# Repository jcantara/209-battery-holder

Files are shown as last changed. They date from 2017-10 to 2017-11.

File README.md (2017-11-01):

# 3D printable cylindrical battery cell holder

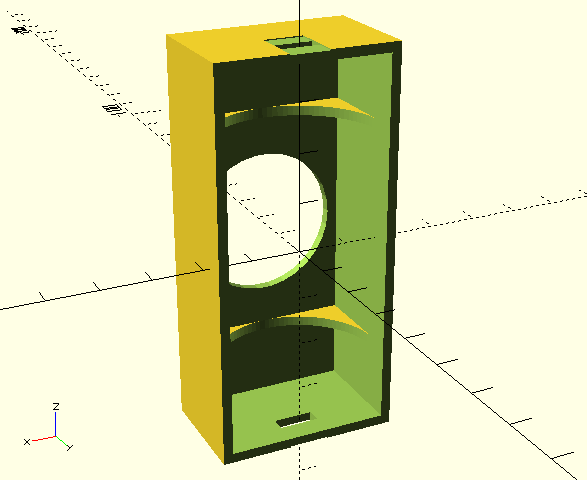
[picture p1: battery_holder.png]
holder-rendering

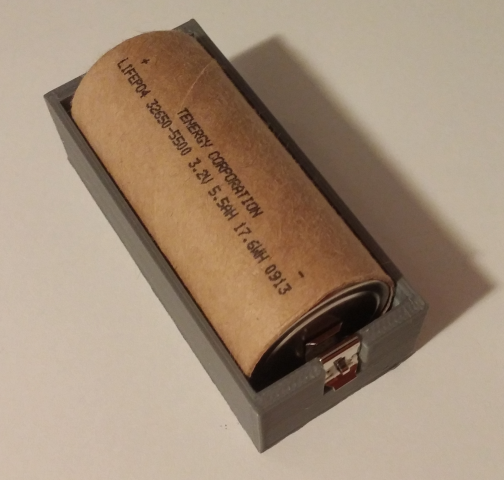
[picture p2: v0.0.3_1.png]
holder-printed

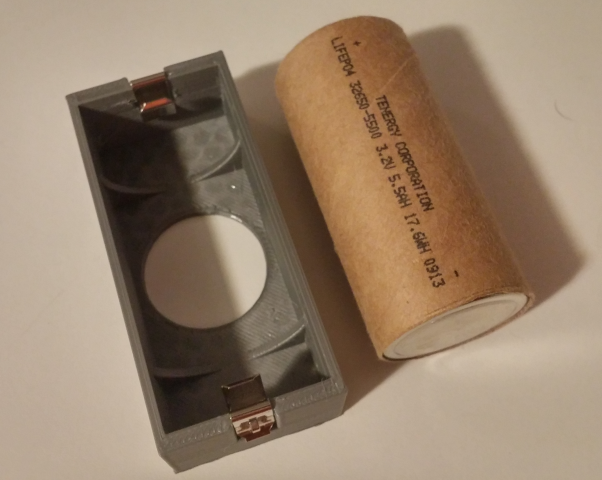
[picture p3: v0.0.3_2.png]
holder-printed2


[Thingiverse thing](https://www.thingiverse.com/thing:2615710)

This is a 3d-printable battery cell holder for cylindrical type cells, currently configured for 32650 LiFePo4 cells which I could not find any existing holders for, however should be fine with adjusted parameters for any 18650 cells, or other "standard" size cylindrical cells such as 18650, D, C, A, etc. This holder is designed around the Keystone 209 battery spring clip, available quite inexpensively from many online electronics parts warehouses such as Digikey, Jameco, Mouser, or others.

## Getting Started

The template is written for OpenSCAD, so you'll need that. It's mostly parameterized, so changing it for other batteries should work out easily. I've printed out the initial version and made some additional tweaks.

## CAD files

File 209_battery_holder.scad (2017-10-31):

// printer-specific fudge setting to allow enough clearance
diameter_fudge = 0.4;

// cell dimensions, measured to 32650 cell in-hand
cell_diameter = 33 + diameter_fudge;
cell_height = 70;

// configured for Keystone "209" clip:
clip_gap = 3.5; // gap between wall of holder and battery where spring clip sits, compressed size
clip_wall = 1.78; // width of printed wall onto which clip clips
clip_top_wall_to_hook = 4.6; // minimum distance between edge of clip wall and hook on clip
clip_width = 8.5;
clip_height = 11.5;

// holder dimensions
wall_thickness = 2.0;
end_wall_thickness = 3.5;

// calculated dimensions
box_width = cell_diameter + wall_thickness*2;
box_height = cell_height + clip_gap*2 + end_wall_thickness*2;
box_depth = cell_diameter + wall_thickness*2;
hole_width = cell_diameter;
hole_height = cell_height + clip_gap*2;
hole_depth = cell_diameter;

// transparent battery image
module battery(cell_height, cell_diameter) {
    cylinder(h=cell_height, d=cell_diameter, center=true, $fn=100);
}
//%battery(cell_height, cell_diameter);


difference(){
    // positive shapes
    union(){
        // main box shape
        difference(){
            cube([box_width, box_depth, box_height], center=true); // box outside
            cube([hole_width, hole_depth, hole_height], center=true); // box cutout
            translate([0,box_depth/2+clip_top_wall_to_hook,0]){cube([box_width+1, box_depth, box_height+1], center=true);} // box top cut off
        }
        // mid supports
        translate([0,-box_depth/4,cell_height/3]){cube([box_width, box_depth/2, wall_thickness],center=true);}
        translate([0,-box_depth/4,-cell_height/3]){cube([box_width, box_depth/2, wall_thickness],center=true);}
    }
    // negative shapes
    union(){
        battery(cell_height, cell_diameter);
        // clip hook hole
        translate([0,-3/2,0]){cube([clip_width, 3, box_height+1], center=true);}
        // clip indentations
        notch_depth = end_wall_thickness-clip_wall;
        translate([0,-(clip_height/2)+clip_top_wall_to_hook,box_height/2-notch_depth/2]){cube([clip_width,clip_height,notch_depth],center=true);}
        translate([0,-(clip_height/2)+clip_top_wall_to_hook,-box_height/2+notch_depth/2]){cube([clip_width,clip_height,notch_depth],center=true);}
        // speed holes
        rotate([90,0,0]){cylinder(h=box_width+1, d=hole_width-4,center=true);}
    }
}

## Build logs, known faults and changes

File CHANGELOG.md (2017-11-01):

# Changelog

All notable changes to this project will be documented in this file

## v0.0.3 - 2017-10-31
### Changed
- Thickened end walls to prevent bowing at spring

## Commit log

2017-10-29 Initial version, not yet printed
    [209_battery_holder.scad]
2017-10-29 Change clip_top_wall_to_hook based on curvature of clip not fitting flush, measured on actual print. Remove the retainer pieces, they don't print well and are of limited use; need to find another ret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
    [209_battery_holder.scad]
2017-10-29 Refactor a lot of it, simplify
    [209_battery_holder.scad]
2017-10-30 Add image of printed holder
2017-10-30 32650 typo fixed
    [209_battery_holder.scad]
2017-10-31 Add extra wall thickness on ends to prevent bending and clearance for clip
    [209_battery_holder.scad, 209_battery_holder.stl]
2017-11-01 Increase end plate thickness to prevent bowing
2017-11-01 Cleanup and add link to thingiverse in readme
    [209_battery_holder.stl]
